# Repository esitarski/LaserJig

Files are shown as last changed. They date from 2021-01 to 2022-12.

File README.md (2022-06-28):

# LaserJig

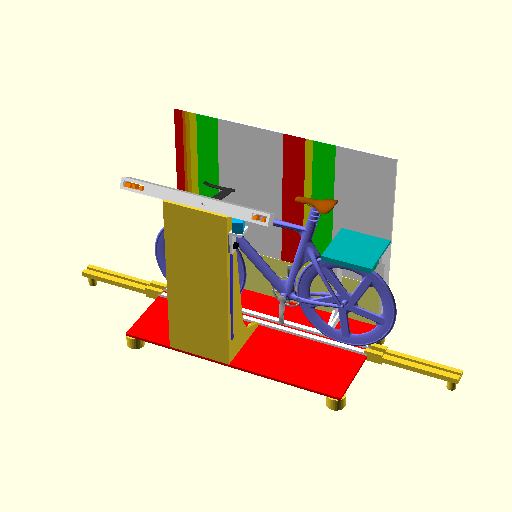
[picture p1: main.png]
LaserJig Rendering


Bike Jig using lasers.  Designed to be used in a fixed location (i.e. a velodrome).
It is heavy and non-portable (about 70kg - 150lbs).
The jig is designed to be "bomb-proof" as it will be subject to
daily abuse while remaining extremely accurate.  Lasers are used for the measuring as they are accurate and contactless.

Updated for the equipment UCI rule changes effective Jan 1, 2023.
In particular, this requires an additional vertical line at 83cm forward of the bottom bracket.

The OpenSCAD files use the lasercut library to output the polygons for the plywood parts via the "prenest.py" script.
A labeled dimensioned parts list is also created main-2d-parts-list.txt.  This makes it easier to determine what all the parts are from their dimentions.

The main-2d-prenest.svg file can be further processed using [Deepnest.io](//https://deepnest.io//) to nest the parts (10mm milling bit separation).
The 3-sheet layout is then processed to create .dxf files that can be processed by a CNC router.

Assembly is relatively straight-forward with biscuit joinery.  The design has a number of assembly-friendly features including some
features to make it easier to orient the parts at assembly.

The laser modules are held in place with aluminum angle and screws which make it possible to fine-tune the accuracy during assembly.
Some critial dimensions are also echoed in the OPENScad output, for example, the position of the column and laser module.

It is important that your CNC router makes highly accurate cuts otherwise the jig will not fit together properly.
Some inaccuracies can be overcome in the final positioning of the lasers.

The design is parameterized in all key dimensions (see params.scad).  It is easy to change for different sized laser modules etc.
Add dimensions are in millimeters.

18mm Birch Plywood is recommended for stability and toughness.  However, if you wish to use a different plywood, just change "sheet_thickness"
in the params.scad file.  All aspects of the design will adjust appropriately.
Be sure to measure the thickness of your material accurately and make sure to express it in mm.

Requires OpenSCAD and Python3 (see requirements.txt for dependent Python modules).

The full design can be viewed in main.scad.  It includes the other module files as required.

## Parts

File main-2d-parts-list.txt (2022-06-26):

back_1: 1
        0.00,    0.00
     1500.00,    0.00
     1500.00,  953.15
        0.00,  953.15
back_2: 1
        0.00,    0.00
     1500.00,    0.00
     1500.00,  317.72
        0.00,  317.72
back_brace_bb: 2
        0.00,    0.00
        0.00,  670.00
      150.50,  670.00
      150.50,  602.00
       90.00,  569.50
       90.00,  100.50
      220.00,   18.00
      220.00,    0.00
back_brace_bb_tab: 2
        0.00,    0.00
        0.00,   50.80
      168.31,   50.80
      220.00,   18.00
      220.00,    0.00
back_brace_hb: 2
        0.00,    0.00
        0.00,  590.00
       18.00,  590.00
       67.50,  489.10
       67.50,  100.50
      220.00,   18.00
      220.00,    0.00
back_brace_hb_tab: 2
        0.00,    0.00
        0.00,   50.80
      159.37,   50.80
      220.00,   18.00
      220.00,    0.00
base: 1
        0.00,    0.00
     1500.00,    0.00
     1500.00,  784.46
        0.00,  784.46
bike_clamp: 1
        0.00,    0.00
      330.00,    0.00
      330.00,  168.50
        0.00,  168.50
bike_clamp_channel: 2
        0.00,    0.00
      330.00,    0.00
      330.00,   50.00
        0.00,   50.00
bike_clamp_support: 1
        0.00,    0.00
      330.00,    0.00
      330.00,  168.50
        0.00,  168.50
bike_clamp_tab: 2
        0.00,    0.00
      245.00,    0.00
      245.00,   50.00
        0.00,   50.00
channel: 2
        0.00,    0.00
     1500.00,    0.00
     1500.00,   33.00
        0.00,   33.00
col_suppport_tab: 3
        0.00,    0.00
        0.00,   50.80
      356.43,   50.80
      427.72,   18.00
      427.72,    0.00
column_front: 1
        0.00,    0.00
      420.00,    0.00
      420.00, 1103.95
        0.00, 1103.95
column_support: 3
        0.00,    0.00
        0.00, 1101.95
       68.22, 1064.14
      191.09,  201.00
      248.41,  100.50
      427.72,   18.00
      427.72,    0.00
column_support_brace_1: 2
        0.00,    0.00
      183.00,    0.00
      183.00,  191.09
        0.00,  191.09
column_support_brace_2: 2
        0.00,    0.00
      183.00,    0.00
      183.00,  129.65
        0.00,  129.65
cross_brace: 6
        0.00,    0.00
      195.67,    0.00
      195.67,   39.00
        0.00,   39.00
electronics_cover: 1
        0.00,    0.00
      183.00,    0.00
      183.00,  427.82
        0.00,  427.82
electronics_cover_block: 2
        0.00,    0.00
       36.00,    0.00
       36.00,  427.82
        0.00,  427.82
laser_shelf: 1
        0.00,    0.00
       75.00,    0.00
       75.00,   85.00
        0.00,   85.00
laser_side: 2
        0.00,    0.00
      710.00,    0.00
      710.00,   37.00
        0.00,   37.00
lasers_bottom: 1
        0.00,    0.00
      940.00,    0.00
      940.00,   60.00
        0.00,   60.00
lasers_end: 2
        0.00,    0.00
       78.00,    0.00
       78.00,   55.00
        0.00,   55.00
lasers_front: 1
        0.00,    0.00
      940.00,    0.00
      940.00,   20.00
        0.00,   20.00
lasers_top: 1
        0.00,    0.00
      976.00,    0.00
      976.00,   78.00
        0.00,   78.00
length_brace: 3
        0.00,    0.00
     1300.00,    0.00
     1300.00,   39.00
        0.00,   39.00
shuttle_extension: 1
        0.00,    0.00
       55.05,    0.00
       55.05,  130.00
        0.00,  130.00
shuttle_rail: 2
        0.00,    0.00
        9.38,    0.00
        9.38,  130.00
        0.00,  130.00
shuttle_shelf: 1
        0.00,    0.00
       75.00,    0.00
       75.00,  103.05
        0.00,  103.05
shuttle_top: 1
        0.00,    0.00
       55.05,    0.00
       55.05,  130.00
        0.00,  130.00
tab_block: 1
        0.00,    0.00
       40.00,    0.00
       40.00,   40.00
        0.00,   40.00
te_base: 2
        0.00,    0.00
      600.00,    0.00
      600.00,  100.00
        0.00,  100.00
te_over: 4
        0.00,    0.00
      120.00,    0.00
      120.00,   33.00
        0.00,   33.00
te_rail: 4
        0.00,    0.00
      600.00,    0.00
      600.00,   33.00
        0.00,   33.00
te_under: 2
        0.00,    0.00
      150.00,    0.00
      150.00,  100.00
        0.00,  100.00
width_brace: 7
        0.00,    0.00
      530.46,    0.00
      530.46,   39.00
        0.00,   39.00

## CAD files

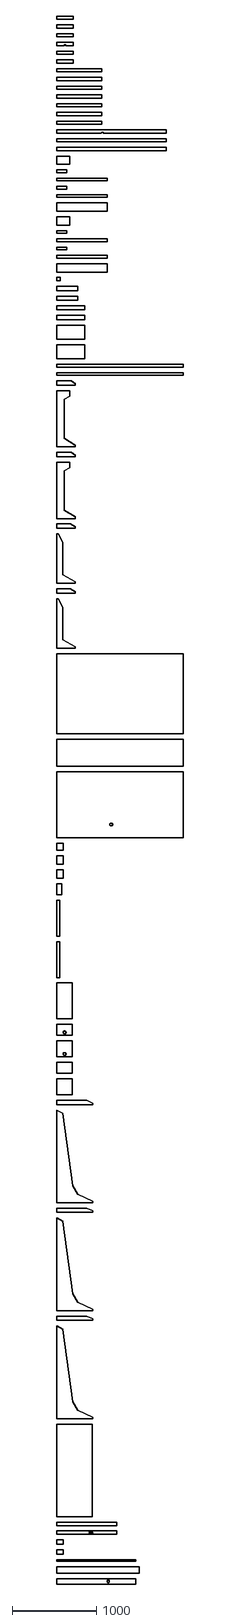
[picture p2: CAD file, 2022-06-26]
main-2d-2.dxf
1500.0 x 18636.7

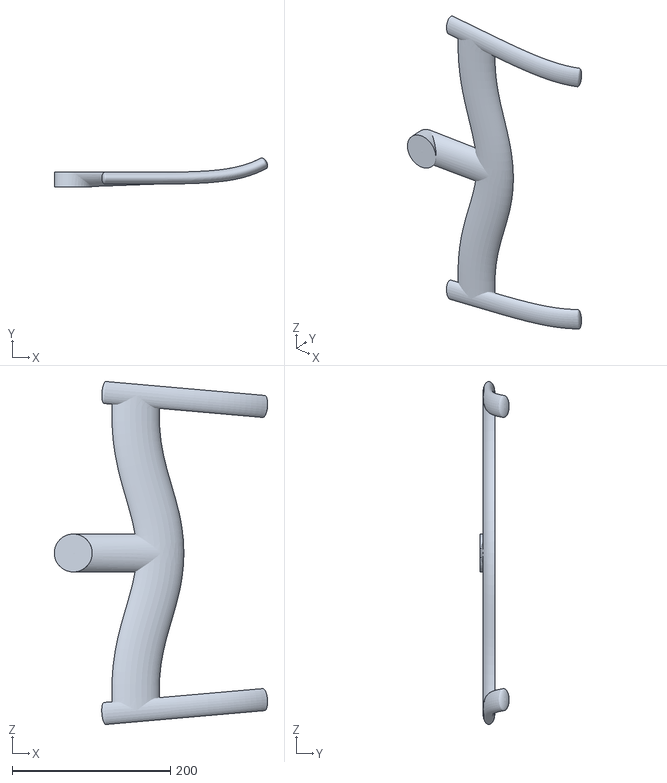
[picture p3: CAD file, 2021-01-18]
TT bike2012 - tt1-brs-1.STL
269.9 x 37.2 x 433.8

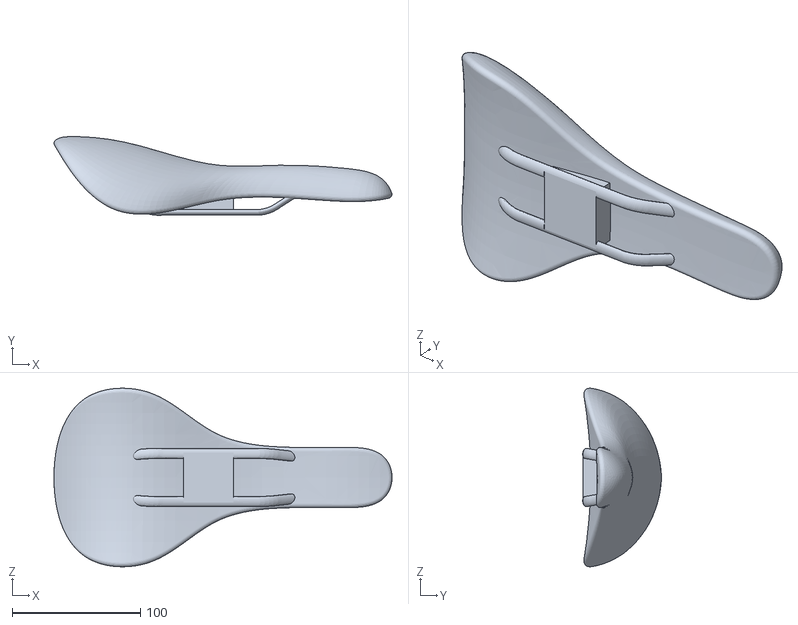
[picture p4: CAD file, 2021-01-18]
TT bike2012 - tt1 saddle-1.STL
263.2 x 61.3 x 139.1

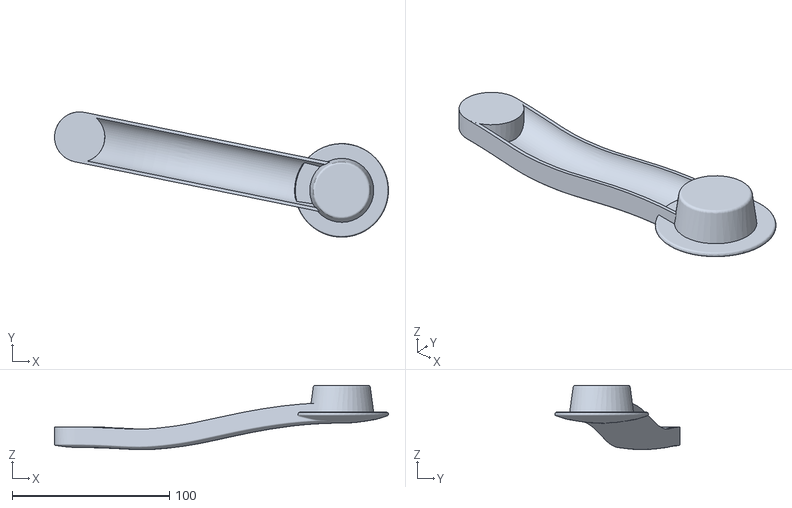
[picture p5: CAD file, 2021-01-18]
TT bike2012 - crankspiderminimalleft-1.STL
212.3 x 79.6 x 40.9

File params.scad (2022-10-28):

sheet_thickness=18;				// thickness of the plywood sheet.
milling_bit=10;                 // size of the milling it (3/8 ~= 10mm)

laser_width=20;					// width of the laser
laser_height=27;				// height of the laser
laser_origin_height=16;			// center of the laser beam
laser_length=60;				// length of the laser (includes cable allowance).
laser_spread_angle = 2*atan((110/2)/60);	// angle the laser spreads out from origin.
plug_diameter = 34;

laser_setback        =  48.45*10-75;	// how much the laser is set back from the center of the bike.
laser_position_z     = 119.26*10-90;	// height of the laser center.
laser_position_angle =  29;		// angle the laser points down.

laser_low = 50;
laser_high=1350;

laser_y = laser_length;

wheel_width=34;					// maximum width of a wheel (space between the wheel channels).
wheel_height=670;				// height of a 700CC wheel.

handlebar_width_max = 500;
channel_offset = handlebar_width_max / 2 + 20;
channel_thickness = 50;         // Thickness of the channels on either side of the week_width.

base_length=1500;

hb_85=50+laser_width/2;			// position of handlebar 85cm line (centered on laser)
hb_83=hb_85+20;					// position of handlebar 83cm line
hb_80=hb_85+50;					// position of handlebar 80cm line
hb_75=hb_80+50;					// position of handlebar 75cm line

bb_0=hb_75+750;					// position of bottom bracket line
bb_5=bb_0+50;					// position of bottom bracket +5cm line

// castor dimensions GD-60F (2" wheel, leveling castor).
castor_height = 82;
castor_radius = 61;
castor_plate = 73;

// bottom of the jig from the floor.
base_bottom = sheet_thickness + castor_height;

tab_height = 2*25.4;	// Height of the tabs to attach the column and back.

// utility functions.

function rotate_point(p,a) = [p[0]*cos(a) - p[1]*sin(a), p[0]*sin(a) + p[1]*cos(a)];

// output the sheet thickness so export.py knows how to created the files.
echo( sheet_thickness=sheet_thickness );

// Global flag indicating to color the parts and background.
color_parts = false;

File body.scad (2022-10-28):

include <column.scad>

clamp_width = 330;

module wheel( x, y, z ) {
    translate([x,y,z])
    rotate([0,90,90])
    cylinder(h=wheel_width, d=wheel_height, center="true");
}

module tandem_extension( p, front ) {
    te_length = 600;
    te_width = channel_thickness * 2;
    te_base = [te_length, te_width, sheet_thickness];
    echo( te_base=te_base );
    te_rail = [te_length, channel_thickness-wheel_width/2, sheet_thickness];
    echo( "2x", te_rail=te_rail );
    te_under = [150, te_width, sheet_thickness];
    echo( te_under=te_under );
    te_over = [120, channel_thickness-wheel_width/2, sheet_thickness];
    echo( "2x", te_over=te_over );
    
    translate( p ) {
        mirror( [front ? 1 : 0, 0, 0] ) {
            cutCube( te_base );
            
            translate( [0, 0, sheet_thickness] ) {
                cutCube( te_rail );
                translate( [-20, 0, sheet_thickness] )
                cutCube( te_over );
            }
            
            translate( [0, te_width-te_rail[1], sheet_thickness] ) {
                cutCube( te_rail );
                translate( [-20, 0, sheet_thickness] )
                cutCube( te_over );
            }

            translate( [-50, 0, -sheet_thickness] )
            cutCube( te_under );
            
            translate( [te_length-50, te_width/2, -p[2]/2])
            cylinder( h=p[2], r=30, center=true );
        }
    }
}

module body() {
    // base
    base_cube = [base_length, base_width, sheet_thickness];
    echo( base_cube=base_cube );
        
    color( [1,0,0] )
    translate( [0,0,base_bottom-sheet_thickness] )
    cutCube( base_cube, circles_remove=[[plug_diameter/2, 645, 155]] );
    
    // back
    back_cube = [base_length, sheet_thickness, back_height];
    
    // Split the back in half horizontally so both parts can be cut from a 4x8 sheet.
    back_1 = [back_cube[0], back_cube[1], back_cube[2]*0.75];
    echo( back_1=back_1 );
    
    back_2 = [back_cube[0], back_cube[1], back_cube[2]*0.25];
    echo( back_2=back_2 );
    
    translate( [0, base_width-sheet_thickness-3, base_bottom] ) {
        color( [1,1,.5] )
        cutCube( back_2 );
        
        translate( [0, 3, back_2[2]] ) {
            color( [1,1,1] )
            cutCube( back_1 );
        }
    }
    
    // back braces
    // hb braces
    back_brace_hb_thickness = channel_offset/4;
    back_brace_hb_y1 = wheel_height*0.73;
    back_brace_hb_y2 = wheel_height*0.15;
    back_brace_hb = [
        [0,0],
        [0,wheel_height-80],
        [sheet_thickness,wheel_height-80],
        [back_brace_hb_thickness,back_brace_hb_y1],
        [back_brace_hb_thickness,back_brace_hb_y2],
        [channel_offset-channel_thickness, sheet_thickness],
        [channel_offset-channel_thickness, 0],
    ];
    echo( "2x", back_brace_hb=back_brace_hb );

    x_max_hb = back_brace_hb[len(back_brace_hb)-1][0];
    y_tab_hb = back_brace_hb[len(back_brace_hb)-3][1] - sheet_thickness;
    x_tab_hb = x_max_hb - back_brace_hb[len(back_brace_hb)-3][0];
    a_tab_hb = atan( y_tab_hb / x_tab_hb );
    back_brace_hb_tab = [
        [0,0],
        [0,tab_height],
        [channel_offset-channel_thickness - (tab_height - sheet_thickness)/tan(a_tab_hb), tab_height],
        [channel_offset-channel_thickness, sheet_thickness],
        [channel_offset-channel_thickness, 0],
    ];
    echo( "2x", back_brace_hb_tab=back_brace_hb_tab );
    
    color( [1,1,1] ) {
        for( x = [0, column_x] ) {
            translate([x+sheet_thickness,
                base_width-sheet_thickness,
                base_bottom])
            rotate([90,0,-90])
            cutPoints( back_brace_hb );
            
            translate([x+(x==0?+sheet_thickness*2:0),
                base_width-sheet_thickness,
                base_bottom])
            rotate([90,0,-90])
           cutPoints( back_brace_hb_tab );
        }
    }
    
    // bb braces
    clamp_y = base_width-sheet_thickness-channel_offset-channel_thickness - wheel_width/2;
    clamp_length = base_width-clamp_y-sheet_thickness;
    clamp_height = base_bottom + wheel_height;
    
    back_brace_bb_thickness = channel_offset/3;
    back_brace_bb = [
        [0,0],
        [0,wheel_height],
        [clamp_length/2-sheet_thickness,wheel_height],
        [clamp_length/2-sheet_thickness,wheel_height-50-sheet_thickness],
        [back_brace_bb_thickness,wheel_height*0.85],
        [back_brace_bb_thickness,wheel_height*0.15],
        [channel_offset-channel_thickness, sheet_thickness],
        [channel_offset-channel_thickness, 0],
    ];
    echo( "2x", back_brace_bb=back_brace_bb );
    
    x_max_bb = back_brace_bb[len(back_brace_bb)-1][0];
    y_tab_bb = back_brace_bb[len(back_brace_bb)-3][1] - sheet_thickness;
    x_tab_bb = x_max_bb - back_brace_bb[len(back_brace_bb)-3][0];
    a_tab_bb = atan( y_tab_bb / x_tab_bb );
    back_brace_bb_tab = [
        [0,0],
        [0,tab_height],
        [channel_offset-channel_thickness - (tab_height - sheet_thickness)/tan(a_tab_bb), tab_height],
        [channel_offset-channel_thickness, sheet_thickness],
        [channel_offset-channel_thickness, 0],
    ];
    echo( "2x", back_brace_bb_tab=back_brace_bb_tab );
    
    color( [1,1,1] ) {
        for( x = [base_length-sheet_thickness,base_length-clamp_width] ) {
            translate([x+sheet_thickness,
                base_width-sheet_thickness,
                base_bottom])
            rotate([90,0,-90])
            cutPoints( back_brace_bb );

            translate([x+(x==base_length-clamp_width?+sheet_thickness*2:0),
                base_width-sheet_thickness,
                base_bottom])
            rotate([90,0,-90])
            cutPoints( back_brace_bb_tab );

        }
    }
    
    // channels.
    channel_cube = [base_length, channel_thickness-wheel_width/2, sheet_thickness];
    echo( "2x", channel_cube=channel_cube );
    
    color( [1,1,1] ) {
        translate( [0, base_width-sheet_thickness-channel_offset-channel_thickness, base_bottom] )
        cutCube( channel_cube );
        
        translate( [0, base_width-sheet_thickness-channel_offset+wheel_width/2, base_bottom] )
        cutCube( channel_cube );
    }
    
    //-------------------------------------------------------
    // back wheel clamp.
    color([0,.7,.7,1]) {
        
        //-----------------------------------
        bike_clamp_support = [clamp_width, clamp_length/2, sheet_thickness];
        echo( bike_clamp_support=bike_clamp_support );
        translate( [base_length-clamp_width, clamp_y+clamp_length/2, clamp_height] )
        cutCube( bike_clamp_support );
        
        //-----------------------------------
        bike_clamp = [clamp_width, clamp_length/2, sheet_thickness];
        echo( bike_clamp=bike_clamp );
        
        translate( [base_length-clamp_width, clamp_y, clamp_height] )
        cutCube( bike_clamp );
        
        //-----------------------------------
        bike_clamp_channel = [clamp_width, channel_thickness, sheet_thickness];
        echo( "2x", bike_clamp_channel=bike_clamp_channel );
        
        // Bike clamp channels.
        translate( [base_length-clamp_width,clamp_y,clamp_height-sheet_thickness] )
        cutCube( bike_clamp_channel );
        
        translate( [base_length-clamp_width,clamp_y+channel_thickness+wheel_width,clamp_height-sheet_thickness] )
        cutCube( bike_clamp_channel );
    }

    color([0,.7,0,1]) {
        // Bike clamp tabs.
        bike_clamp_tab = [sheet_thickness, channel_offset-wheel_width/2-8, 50];
        echo( "2x", bike_clamp_tab=bike_clamp_tab );
        
        translate([base_length-sheet_thickness*2,base_width-bike_clamp_tab[1]-sheet_thickness,clamp_height-bike_clamp_tab[2]-sheet_thickness])
        rotate( [3,0,00] )
        cutCube( bike_clamp_tab );
        
        translate([base_length-clamp_width+sheet_thickness,base_width-bike_clamp_tab[1]-sheet_thickness,clamp_height-bike_clamp_tab[2]-sheet_thickness])
        rotate( [3,0,00] )
        cutCube( bike_clamp_tab );
        
    };
    
    // Brace tab
    tab_block =  [sheet_thickness,40,40];
    echo( tab_block=tab_block );
    color([0,1,1]) {
        translate( [base_length-clamp_width, base_width-tab_block[1]-back_brace_bb_tab[2][0]+1.25*sheet_thickness, clamp_height-tab_block[2]-sheet_thickness] )
        cutCube( [sheet_thickness,40,40] );
    }
    
    if( color_parts ) {
        translate( [0, base_width-sheet_thickness-1, base_bottom] )
        color( [1,0,0] )
        cube( [hb_85-0, 1, back_height] );
        
        translate( [hb_85, base_width-sheet_thickness-1, base_bottom] )
        color( [1,.5,0] )
        cube( [hb_83-hb_85, 1, back_height] );

        translate( [hb_83, base_width-sheet_thickness-1, base_bottom] )
        color( [1,.75,0] )
        cube( [hb_80-hb_83, 1, back_height] );

        translate( [hb_80, base_width-sheet_thickness-1, base_bottom] )
        color( [1,1,0] )
        cube( [hb_75-hb_80, 1, back_height] );
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

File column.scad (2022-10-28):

include <lasers.scad>
include <thickness.scad>
include <lasercut/lasercut.scad>

laser_reveal = 165;
column_width = bb_0 - hb_75 - laser_reveal * 2;
column_height = laser_position_z+lasers_back_yz[1];

column_x = (bb_0+hb_75-column_width)/2;

laser_level_spread_angle = 110;

module horizontal_laser_line() {
	a = laser_level_spread_angle/2;
    y = 1000 * tan(a);
	points = [
		[0,0],
		[-y, 1000],
		[y, 1000],
	];
	color( [0,1,0,.05] ) {
        linear_extrude( height=1 )
        polygon( points );
	}
}

module horizontal_laser( x, p_bottom, p_top ) {
    track = [3/8*25, 3/4*25.4, 800];
    laser = [65, 70, 75];
    bolt_xy = [65/2, 40];
    laser_height = 45;
    
    rail_length = 130;
    shuttle_rail = [track[0], sheet_thickness, rail_length];
    shuttle_top = [sheet_thickness, sheet_thickness*2+track[1], shuttle_rail[2]];
    shelf_border = 10;
    laser_shelf = [laser[0]+shelf_border, laser[2]+shelf_border,sheet_thickness];
    shuttle_extension = [laser_shelf[0],sheet_thickness,100];
    shuttle_shelf = [laser[0]+shelf_border, shuttle_top[1]+30+sheet_thickness, sheet_thickness];
    
    dx = p_top[0] - p_bottom[0];
    dy = p_top[1] - p_bottom[1];
    angle = 0;
    
    fraction = 0.0;
    p_bottom_new = [p_bottom[0] + dx*fraction-140, p_bottom[1] + dy*fraction-25];
    
    echo( "shuttle_angle=", angle );
    echo( "shuttle_height=", p_bottom_new[0] );
    
    echo( "2x", shuttle_rail=shuttle_rail );
    echo( shuttle_top=shuttle_top );
    echo( shuttle_extension=shuttle_top );
    echo( laser_shelf=laser_shelf );
    echo( shuttle_shelf=shuttle_shelf );
        
    translate( [x,p_bottom_new[0],base_bottom+p_bottom_new[1]] ) {
        rotate( [angle,0,0] ) {
            color( [.25,.25,1] )
            translate( [0,-sheet_thickness, 0] )
            cube( track );
            
            //shuttle_height = track[2]/2;
            shuttle_height = track[2] - shuttle_rail[2];
            
            color( [.5,.5,.5] )
            translate( [0,0, shuttle_height] )
            cube( shuttle_rail );
                
            color( [.5,.5,.5] )
            translate( [0, -track[1] - sheet_thickness, shuttle_height] )
            cube( shuttle_rail );

            color( [1,1,1] )
            translate( [track[0], -track[1] - sheet_thickness, shuttle_height] )
            cutCube( shuttle_top );
            //cube( shuttle_top );

            translate( [track[0], -track[1] - sheet_thickness, shuttle_height+shuttle_rail[2]] ) {
                rotate( [-angle,0,0] ) {
                    color( [1,1,1] )
                    cutCube( shuttle_shelf );
                    
                    color( [0,0,0] )
                    translate( [sheet_thickness, shuttle_shelf[0]/2-10, -shuttle_height/8] )
                    rotate( [0,90,0] )
                    cylinder( h=40, r=20, center=true );

                    translate( [laser_shelf[0]/2,laser_shelf[1]/2, sheet_thickness+laser[2]/2] ) {
                        rotate( [0,0,17] ) {
                            color( [0,.75,1] )
                            cube( laser, center=true );
                        
                            translate([0, laser[1]/2, laser[2]*.25]) {
                                if(show_laser_lines ) {
                                    horizontal_laser_line();
                                }
                            }
                        }
                    }
                }
            }
        };
    };
}

module column() {
        // Add a lip on the column front for alignment.
    column_front = [column_width, sheet_thickness, column_height+2];
    
    echo( column_front=column_front );
    
    column_laser_x = laser_reveal + hb_75-hb_85 + laser_clearance + sheet_thickness;
    echo( column_laser_x=column_laser_x );
    
    echo( hb_85=hb_85 );
    
    column_support_break_y = (lasers_effective_width + laser_setback)/2.5;
    column_support_break_y2 = column_support_break_y*1.3;
    column_support_break_z = .15*wheel_height;
    column_support_break_z2 = .30*wheel_height;
    column_support_z2 = column_height-abs(lasers_back_yz[1]-lasers_front_yz[1]);
    column_support = [
        [0,0],
        [0,column_height],
        [lasers_effective_width,column_support_z2],
        [column_support_break_y,column_support_break_z2],
        [column_support_break_y2,column_support_break_z],
        [lasers_effective_width + laser_setback-channel_thickness,sheet_thickness],
        [lasers_effective_width + laser_setback-channel_thickness,0]
    ];
    echo( "3x", column_support=column_support );
       
    //---------------------------------------------------------------
    translate( [0, 0, base_bottom] ) {
        // Compute the tabs to attach the supports to the base.
        x_max = column_support[len(column_support)-1][0];
        y_tab = column_support[len(column_support)-3][1] - sheet_thickness;
        x_tab = x_max - column_support[len(column_support)-3][0];
        a_tab = atan( y_tab / x_tab );
        
        echo( column_x=column_x );
        translate( [column_x,0,0] )
        cutCube( column_front );
    
        col_suppport_tab = [
            [0,0],
            [0,tab_height],
            [x_max - (tab_height - sheet_thickness)/tan(a_tab),tab_height],
            [x_max,sheet_thickness],
            [x_max,0],
        ];
        echo( "3x", col_suppport_tab=col_suppport_tab );
        
        column_support_spacing = (column_width - sheet_thickness) / 2;
        translate( [column_x, sheet_thickness, 0] ) {
            for( i = [0:2] ) {
                translate([i*column_support_spacing,0,0])
                rotate([90,0,90])
                cutPoints( column_support );

                translate([i*column_support_spacing+(i==2?-sheet_thickness:sheet_thickness),0,0])
                rotate([90,0,90])
                cutPoints( col_suppport_tab );
            }
        }
        
        column_support_brace_1 = [
            (column_width - 3*sheet_thickness)/2,
            column_support_break_y,
            sheet_thickness
        ];
        column_support_brace_2 = [
            (column_width - 3*sheet_thickness)/2,
            (column_support_break_y+lasers_effective_width)/2,
            sheet_thickness
        ];
        echo( "2x", column_support_brace_1=column_support_brace_1 );
        echo( "2x", column_support_brace_2=column_support_brace_2 );
        
        column_support_brace_height_1 = column_support_break_z2-sheet_thickness;
        column_support_brace_height_2 = (column_support_z2+column_support_break_z)/2;
        echo( column_support_brace_height_1=column_support_brace_height_1,
            column_support_brace_height_2=column_support_brace_height_2 );
        
        color( [1,0,0,.2] )
        translate( [column_x, 0, 0] )
        for ( x = [sheet_thickness, (column_width+sheet_thickness)/2] ) {
            translate( [x, sheet_thickness, column_support_brace_height_1] )
            if( x != sheet_thickness ) {
                cutCube(
                    column_support_brace_1,
                    circles_remove=[[plug_diameter/2, column_support_brace_1[0]/2, sheet_thickness+plug_diameter/2]] );
            }
            else
                cutCube( column_support_brace_1 );
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

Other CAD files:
HandlebarGauge.scad
HandlebarGaugeManual.scad
laser_clamp.scad
lasercut/lasercut.scad
lasers.scad
main-2d-2.scad
main-test.scad
main.scad
support.scad
thickness.scad

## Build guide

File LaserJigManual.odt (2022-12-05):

Using the Laser Bike Jig

Edward Sitarski

edward.sitarski@gmail.com

October, 2022

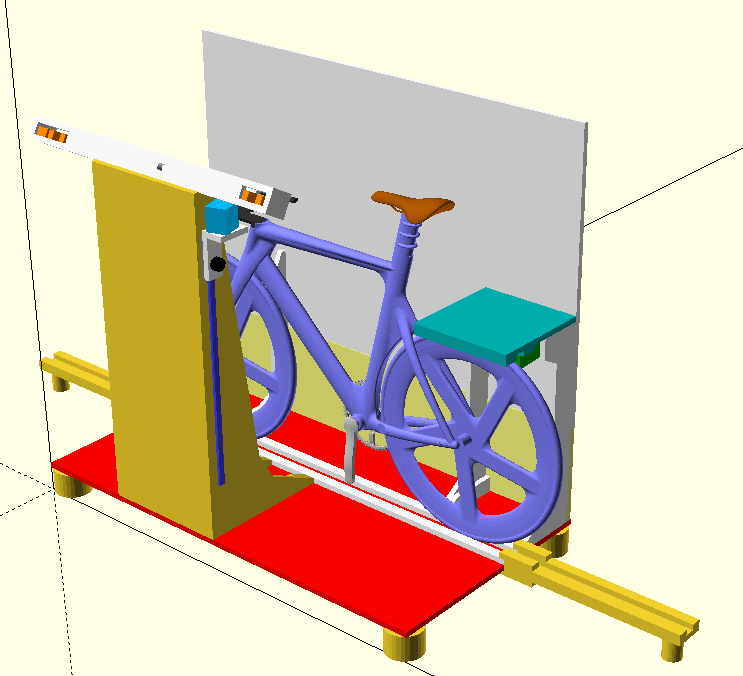
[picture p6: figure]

Using the Laser Bike Jig

# Using the Laser Bike Jig

## Introduction

The Laser Bike Jig is designed to check that Time Trial and Mass Start/Sprint bikes are compliant with the UCI rules effective January 1st, 2023.

This document does not cover specifics about the UCI equipment rules or how they are applied. Please consult the latest UCI rules available on the www.uci.org website.

The Laser Bike Jig is very fast, accurate and easy to use. It is possible to check dozens of bikes in a few minutes.

The Laser Bike Jig is a precision instrument. Treat it with care.

It uses Class 2 lasers similar to laser levels. Never look directly into any laser.

Be responsible. Do not leave the jig unsupervised - especially if children are present. It is not a toy. Use the key to turn it off (and/or unplug it) when it is unattended.

The jig primarily consists of the laser column (the part in front with the lasers), the trapdoor lid (holds the back wheel), the backboard (the board the lasers shine on) and the tandem extensions (used to extend the bike jig track to accommodate tandem bicycles). See the diagram on the cover page.

### Moving, Locking and Leveling

Roll the bike jig to where it is needed.

Lock and level the bike jig. The jig has “leveling castors” with a thumb wheel that raise and lower a rubber foot (see photo). When all feet are lowered, the jig cannot move.

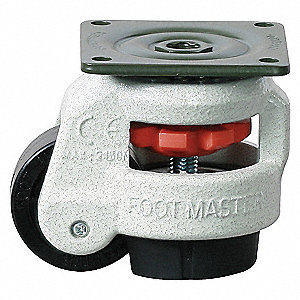
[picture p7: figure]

Lower the feet by turning the thumb wheel in the opposite direction to the green arrows shown on the base of the jig. Use the feet to level the jig by adjusting them to different heights. It is important for the bike jig to be level.

To move the bike jig again, rotate all the thumb wheels in the direction of the green arrows until they cannot be turned anymore. This retracts the feet fully and the bike jig will roll freely.

### Operating the Bike Jig

Ensure the bike jig is plugged in to a working outlet. The start button should be outlined in green. If the bike jig fails to operate, try another outlet that is known to be working.

Press the button. This activates the lasers for 2 minutes, then turns them off automatically. Pressing the button while the lasers are on will restart the timer again.

The horizontal laser on the right side is controlled with its own switch on top.

There is a key that disables/enables the bike jig. The lock must be in the ON position for the jig to work.

Do not let anyone stand on the jig while measuring a bike. Standing on the jig causes it to deflect and will result in inaccurate measurements.

### Laser Lines

Review the UCI rules 1.3.022 and 1.0.023. Note there are 3 Classes of riders based on height (Class 1: <180cm, Class 2: 180-190cm, Class 3: >=190cm).

The laser bike jig generates 7 lasers lines: 6 vertical lines and one horizontal line.

The vertical laser lines are as follows, from left to right:

Distance | Used For
850mm | Class 3 TT handlebar limit
830mm | Class 2 TT handlebar limit
800mm | Class 1 TT handlebar limit
750mm | Default TT handlebar limit
0mm | Center of Bottom Bracket
50mm | Saddle setback

The 750mm and 850mm line have secondary labels as follows:

Distance | Used For
100mm | Mass Start/Sprint Bike handlebar limit
0mm | Center of Front Wheel Spindle

These lines are used to check the maximum horizontal distance of the handlebars to the front wheel spindle (1.34.022).

There is also a horizontal laser line on an adjustable track on the right of the laser column. This is used to check that the handlebars are lower than the peak of the saddle.

As the horizontal line is not always required, this laser has its own switch on the top.

### Time Trial Handlebar Extension Gauge

Time trial handlebar extensions are measured with the Plexiglass gauge.

It can be found in a bracket on the inside of the laser column.

The gauge is marked with +/-100mm, +/-120mm and +/-140mm lines corresponding to Class 1, 2 and 3 riders (see UCI rule 1.0.023).

It also contains useful measurements for other rules (min/max saddle length, etc.).

See the Time Trial Bikes section for details.

Always return the Time Trial Handlebar Extension Gauge to the bracket when not in use.

### Digital Level

Used to measure seat angle as well as forearm support angle for time trial handlebar extensions.

It can be found on a shelf on the inside of the laser column.

### Electrical Power on the Bike Jig

There are two available outlets at the base of the laser column as part of its extension cord. These can be used for a fan or a power supply (for example, recharging a tablet or operating a computer).

## Checking Mass Start and Sprint Bikes

1. Lift the trapdoor lid on the right.
2. Put the bike in the jig making sure the tires are in the track. The handlebars are on your left.
3. Lower the trapdoor lid onto the back wheel so that it is in the track. The bike is now held securely in the jig.
4. Adjust the bike forwards/backwards so at the 0mm laser (second from the right) is perfectly aligned on the center of the bottom bracket. The bike should look as above.

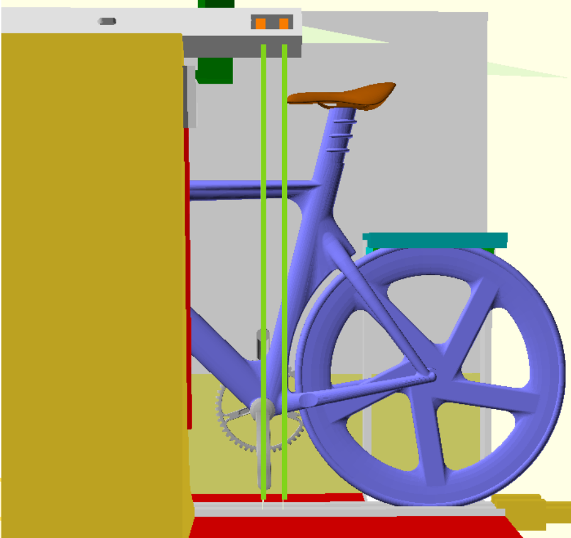
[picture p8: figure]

5. Check that the saddle tip is behind the 0mm line. Check if the saddle is ahead of the 50mm line (a morphological exception).
6. Check the saddle angle by putting the Plexiglass gauge on the saddle, then put the digital level on top of that.
7. Check that the handlebars are lower than the saddle. Turn on the horizontal level by pressing the button on the top, loosen the knob, slide the laser so the line is at the top of the saddle, then tighten the knob again. It does not take a lot of force to tighten it, so be gentle.

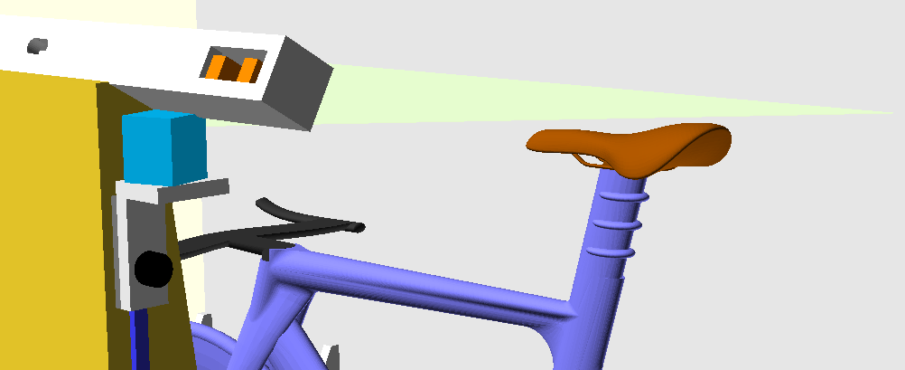
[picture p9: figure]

8. With the bike still in the jig, roll the bike forward so the front wheel spindle is centered on the 0mm (750mm) vertical line. It should like as above.

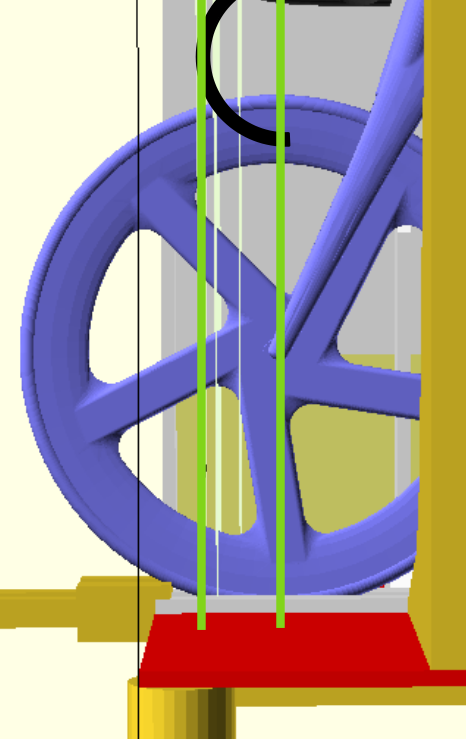
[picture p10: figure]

9. Check that the handlebars are within the 100mm (850mm) vertical line limit.
10. Roll the bike out of the jig to the left.

Notes:

The above steps are a recommendation only. Skip steps that are obviously not required, or add steps you feel are necessary.

To check many bikes quickly, try skipping using the trapdoor. Most bikes will lean against the jig and will be stable enough to measure.

Some bikes (eg. Hope/Lotus) have a shape that gets in the way of one of the trapdoor support tabs. This tab can be moved out of the way by releasing the latch with the red handle and folding the tab inward. Secure the tab with the latch to its normal position when finished.

## Checking Time Trial Bikes

1. Lift the trapdoor lid on the right.
2. Put the bike in the jig making sure the tires are in the track. Ensure the handlebars are on the left.
3. Lower the trapdoor lid onto the back wheel so that it fits in the track. The bike is now held securely in the jig.
4. Adjust the bike forwards/backwards so at the 0mm laser (second from the right) is centered on the bottom bracket. It should look as above.
5. Check that the saddle behind the 0mm line. Check whether the saddle is in front of the 50mm line. If so, this is a morphological exception.
6. Check the saddle angle by putting the Plexiglass gauge on the saddle, then put the digital level on top.
7. Check that the handlebars are lower than the saddle. Turn on the horizontal level by pressing the button on the top, loosen the handle, slide it so the line is at the top of the saddle, then tighten the handle again. It does not take a lot of force to tighten it. Handlebar extensions are exempt and can be above the saddle height.
8. Review the Class of the rider based on height.
9. Check that the handlebar extension length conforms to the rules for the rider Class as specified in UCI rule 1.0.023. To do so, check the appropriate laser lines at the 750mm, 800mm, 830mm and 850mm on the left side of the jig. Do not move the bike from its alignment on the bottom bracket laser. The handlebar extension check should look as above.

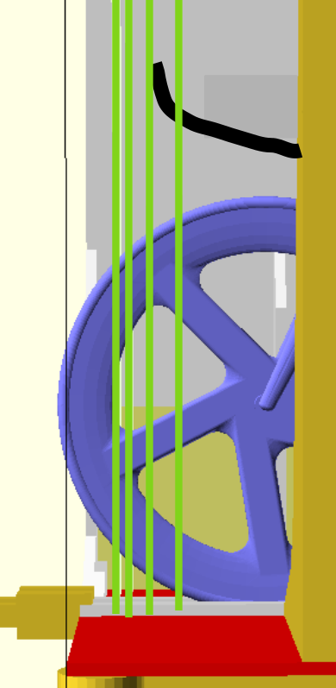
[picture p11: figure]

10. Check that the angle of the forearm supports with the digital level.
11. Use the Plexiglass gauge to check the maximum +/- dimensions of the extensions. Orient the gauge corner so it contacts the middle of the forearm support as shown in the diagram. Ensure the gauge is level by using the bubble indicator, then check that the handlebar extensions are within +/- 10cm, +/- 12cm or +/- 14cm based on the 1, 2, 3 rider Class.

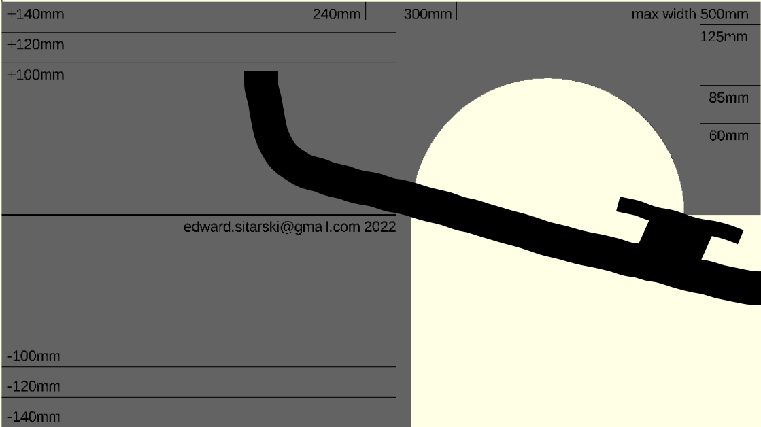
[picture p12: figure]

Notes:

The above steps are a recommendation only. Skip steps that are obviously not required, or add steps you feel are necessary.

Some bikes are so wide that one of the support tabs is in the way. To move this tab, release the latch with the red handle and push the tab inward. Secure the tab back to its normal position with the latch when finished.

## Checking Tandem Bikes

1. Install the tandem track extensions.
2. Remove both tandem extensions from under the trapdoor lid.

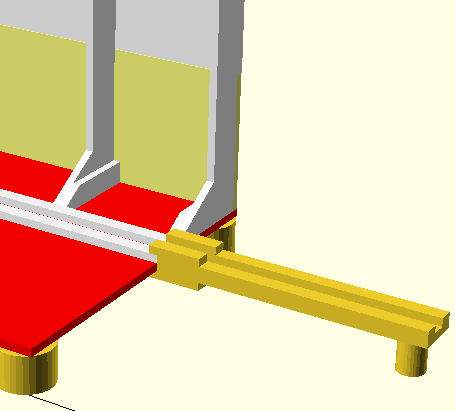
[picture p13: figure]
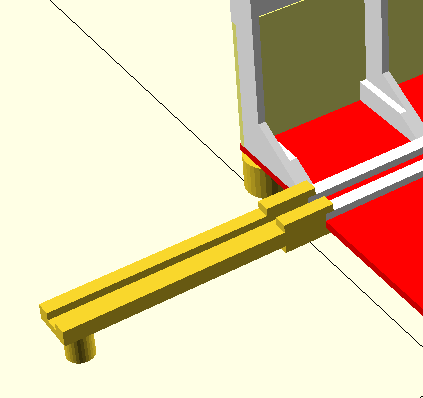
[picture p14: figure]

3. Hook the extensions to the bike jig track. Ensure that the tracks are aligned. See above for details. Figure 2: Right Side Figure 1: Left Side
4. Twist the foot on the leg of each extension until the track is completely level. Using the bubble levels.

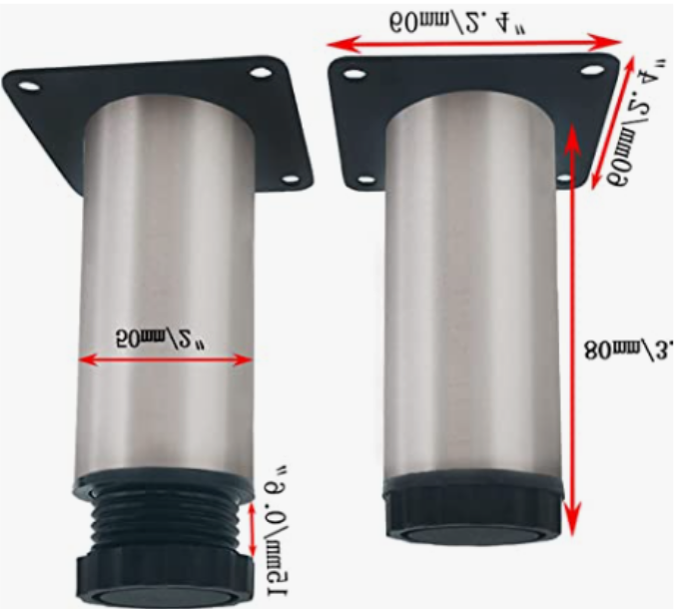
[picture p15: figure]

5. Lift up the trapdoor lid and leave it in the up position.
6. Put the tandem bike in the jig, align the front rider’s bottom bracket, and do the same checks for Time Trial bikes.
7. Roll the tandem bike forward, align the rear rider’s bottom bracket, and check the seat position and angle. You can use the trapdoor lid to hold the bike when checking the rear rider.
8. When finished checking tandem bikes, return the track extensions to their position under the trapdoor lid.

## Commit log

2021-01-18 Initial commit.
    [BikeJig.dxf, TT bike2012 - crankspiderminimalleft-1.STL, TT bike2012 - tt1 saddle-1.STL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]
2021-01-18 updated again.
    [BikeJig.dxf]
2021-01-19 Sorted the output shapes to make it easier to see if everything is there.
    [BikeJig.dxf]
2021-01-20 Changed sheet thickness to 18mm.
    [params.scad]
2021-01-20 Updated to 18mm thickness.
2021-01-22 Added mounting tabs to the front and back to enable disassembly for transport.
    [body.scad, column.scad, lasers.scad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]
2021-01-23 Adjusted supports for base.
    [support.scad]
2021-01-23 Added dxf and svg files.
    [LaserJig.dxf]
2021-01-24 Added an svg file with a sheet (for use with nesting).
    [LaserJig.dxf]
2021-01-24 Split the back so it fits into a 4x8 plywood sheet.
    [LaserJig.dxf, body.scad]
2021-01-24 Added back stiffener.
    [LaserJig.dxf, body.scad]
2021-01-24 Updated generated files.
    [LaserJig.dxf]
2021-01-24 Added outlines to the svg objects.
    [LaserJig.dxf]
2021-01-24 Added outlines.
    [LaserJig.dxf]
2021-01-24 Fixed polyline to polygon to make closed svg shapes.
    [LaserJig.dxf]
2021-01-24 Lowered the lasers slightly so the column pieces can fit into a 4' sheet.
    [LaserJig.dxf, lasers.scad, params.scad]
2021-01-24 Added a brace strut so the hb brace does not get broken in transit.
    [LaserJig.dxf, body.scad]
2021-01-25 Changed the back so the seam is horizontal, not vertical. Because we already have the veritcal supports, this avoids the need for any other braces.
    [LaserJig.dxf, body.scad]
2021-01-25 Added sheet nestings.
    [LaserJigSheet_1.dxf, LaserJigSheet_2.dxf, LaserJigSheet_3.dxf]
2021-01-28 Finalized dimensions of the leveling castors.
    [LaserJigSheet_1.dxf, LaserJigSheet_2.dxf, LaserJigSheet_3.dxf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]
2021-01-28 Adjusted castor offset.
    [params.scad, support.scad]
2021-01-28 Updated comment.
    [LaserJig.dxf, params.scad]
2021-01-28 Updated leveling cstor dimensions.
    [params.scad, support.scad]
2021-01-28 Updated after export.
    [LaserJig.dxf]
2021-01-28 Adjusted ground clearance.
    [LaserJig.dxf, support.scad]
2021-01-28 Rounded support coords for easier assembly.
    [LaserJig.dxf, support.scad]
2021-01-28 Updated to ceil function.
    [LaserJig.dxf, support.scad]
2021-01-28 New nesting for the updated design.
    [LaserJig.dxf, LaserJigSheet_1.dxf, LaserJigSheet_2.dxf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]
2021-01-30 Added offset to castors to avoid screw pull-out from being too close to the edge.
    [LaserJig.dxf, support.scad]
2021-01-30 Renested design changes.
    [LaserJigSheet_1.dxf, LaserJigSheet_2.dxf, LaserJigSheet_3.dxf]
2021-01-31 Better parts nesting.
    [LaserJigSheet_1.dxf, LaserJigSheet_2.dxf, LaserJigSheet_3.dxf]
2021-02-18 Changed wheel width to 34mm to accomodate new wider TT wheels.
    [LaserJig.dxf, params.scad]
2021-02-18 Updated nesting to reflect wheel size change.
    [LaserJigSheet_1.dxf, LaserJigSheet_2.dxf, LaserJigSheet_3.dxf]
2021-02-24 Simplified the laser support. Added a part list to export.py
    [LaserJig.dxf, lasers.scad]
2021-03-01 Added additional reference points to output.
    [LaserJig.dxf, column.scad, lasers.scad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]
2021-03-25 Added extensions for tandem.
    [LaserJig.dxf, body.scad, lasers.scad]
2021-03-30 Added outriders for tandems.
    [LaserJig.dxf]
2021-04-08 Added horizontal laser level to check for seat under handlebars.
    [LaserJig.dxf, column.scad, lasers.scad]
2021-04-14 Fixed bug in export when regular comments.
    [LaserJig.dxf, column.scad]
2022-06-26 Updated for new UCI rules.
    [HandlebarGauge.scad, HandlebarGaugeManual.scad, LaserJig.dxf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]
2022-06-26 Removed old files. Fixed problem in laser location.
    [HandlebarGauge.scad, LaserJig.dxf, LaserJigSheet_1.dxf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]
2022-06-28 Added credits.
    [HandlebarGauge.scad, HandlebarGaugeManual.scad, lasers.scad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]
2022-06-30 Added 2-d definition for HandlebarGauge.
    [HandlebarGauge.scad, HandlebarGaugeManual.scad]
2022-07-06 Updated cutting -> scoring.
    [HandlebarGauge.scad, HandlebarGaugeManual.scad]
2022-07-07 Updated scoring files to use <line> for the indicator lines, not shapes.
    [HandlebarGauge.scad, HandlebarGaugeManual.scad]
2022-07-07 Re-enabled text.
    [HandlebarGaugeManual.scad]
2022-10-28 Updated horizontal line laser design.
    [body.scad, column.scad, lasers.scad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]
2022-10-28 Updated documentation.
    [params.scad]
2022-12-05 Added 350mm mark for minimum handlebar width.
    [HandlebarGauge.scad, HandlebarGaugeManual.scad]
